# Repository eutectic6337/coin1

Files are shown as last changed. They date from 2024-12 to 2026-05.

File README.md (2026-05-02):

# coin1
challenge coin with blinky lights

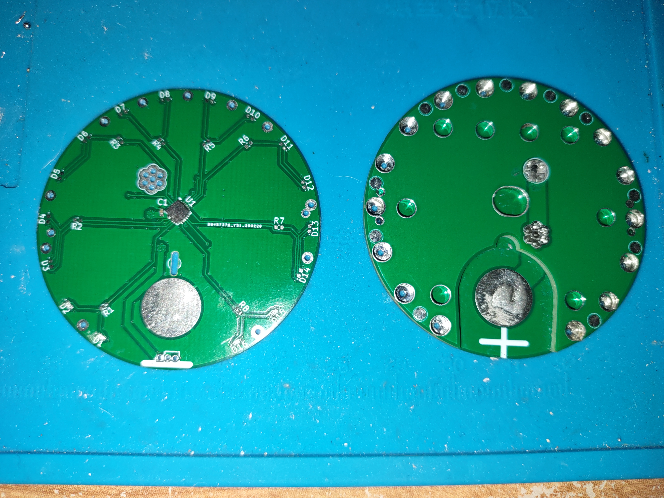
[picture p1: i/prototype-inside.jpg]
pre-DEFCON prototype, from the inside


Feature: Using 8 PWM channels to provide dimming function for 16 LEDs
by connecting pairs in anti-parallel between a PWM pin and a GPIO.

built as a stack of 3 PCBs -
components mounted on top of bottom board,
second board has a cutout to fit a battery and for each mounted component,
and top board has holes to transmit light from LEDs

finished coin to have [relatively] smooth top and bottom

using JLCPCB's serial-number mechanism to put a unique number on each coin

Initial code flashed onto these is
[a modified version of the Arduino Blink demo](software/Blink).

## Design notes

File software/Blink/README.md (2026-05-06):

# Blink

Arduino demo, modified to loop over 8 pairs of
anti-parallel-connected LEDs,
blinking each one on for 1ms and off for 99ms
before moving on to the next.

## How to build and flash the software on the chip

### What to get

- [Arduino IDE](https://www.arduino.cc/en/software/#ide)

- WCH compiler

  First, add the unofficial WCH repo: In Arduino IDE > File > Preferences > Additional Board Manager URLs > Click the 'Edit' icon on the far right side of the IDE (It looks like a copy button)
  Always double check the JSON by clicking 'Click for a list of unofficial board support URLs', but the .json link is listed below:
  https://raw.githubusercontent.com/openwch/board_manager_files/main/package_ch32v_index.json

  You must install v1.0.0 first or you will run into errors. After that, install v1.0.4. (If you run into issues, run the IDE with elevated privs)

  within Arduino IDE, select Tools / Board / Boards Manager

  search for "wch"

  install "CH32 MCU EVT Boards"

- [WCH-LinkUtility](https://www.wch.cn/downloads/WCH-LinkUtility_ZIP.html)
 programming tool

   (works on Linux under WINE)

- [WCH-LinkE](https://www.aliexpress.us/item/3256804695267285.html)
 USB programmer

- 3-pin 1.27mm spacing
 [pogo-pin PCB clip](https://www.aliexpress.us/item/3256806702127807.html)

- some Dupont-connector jumper wires

### What to do

- open this modified Blink sketch in Arduino environment, and compile it by clicking leftmost button "Verify"

  find the generated bin file (e.g. /home/user/.cache/arduino/sketches/40EA08CCBD0DF8AB898F31F63E3E5F1E/Blink.ino.bin)
                              (e.g. C:\Users\USER\AppData\Local\arduino\sketches\40C10A2A9890BEF7BEAD8C7F314D8C2A/sketch_[DATE].ino.bin)

- connect 3V, GND, and SWDIO pins on WCH-LinkE device to 3 pins on PCB clip,
 from right to left respectively, so the pogo pins can contact the pads on the
 back face of the coin (the back of the PCB with components mounted)

- plug WCH-LinkE in to USB port on PC

- run WCH-LinkUtility

  load the bin file (see above) using first button "Choose"
  connect to WCH-LinkE using second button "Connect" (should soon see status message similar to "Connected RISC-V mode WCH-Link Cnt:0")

  select Core "RISC-V"

  select Series "CH32V003"

- in "Operation" section

  check "Erase All", "Program", "Verify", "Reset and Run"

- in "Operation Configuration" section

  select "Disable MCU Code Read-Protect"

  select from dropdown CLK Speed "High"

- in "MCU Configuration" section

  check "Disable Standby-Mode RST" (Note: Need to clarify whether we're unchecking 'Starting From the Boot Area')

  select from dropdown "Disable mul-func,PD7 is used for IO function"

### then for each coin

- connect PCB clip to coin

  verify connection using third button "Query Chip Info"
 (should soon see status messages "Begin to set chip type...", "Begin to get chip version...", "Begin to get chip UID & flash size...")
")

  program chip using fourth button "Execute"
 (should soon see status messages "Begin to set chip type...", "Begin to Erase...", "Begin to Program and Verify...", "Begin to Reset...", "Operation is Successful")

  sit back und watchen das blinkenlights

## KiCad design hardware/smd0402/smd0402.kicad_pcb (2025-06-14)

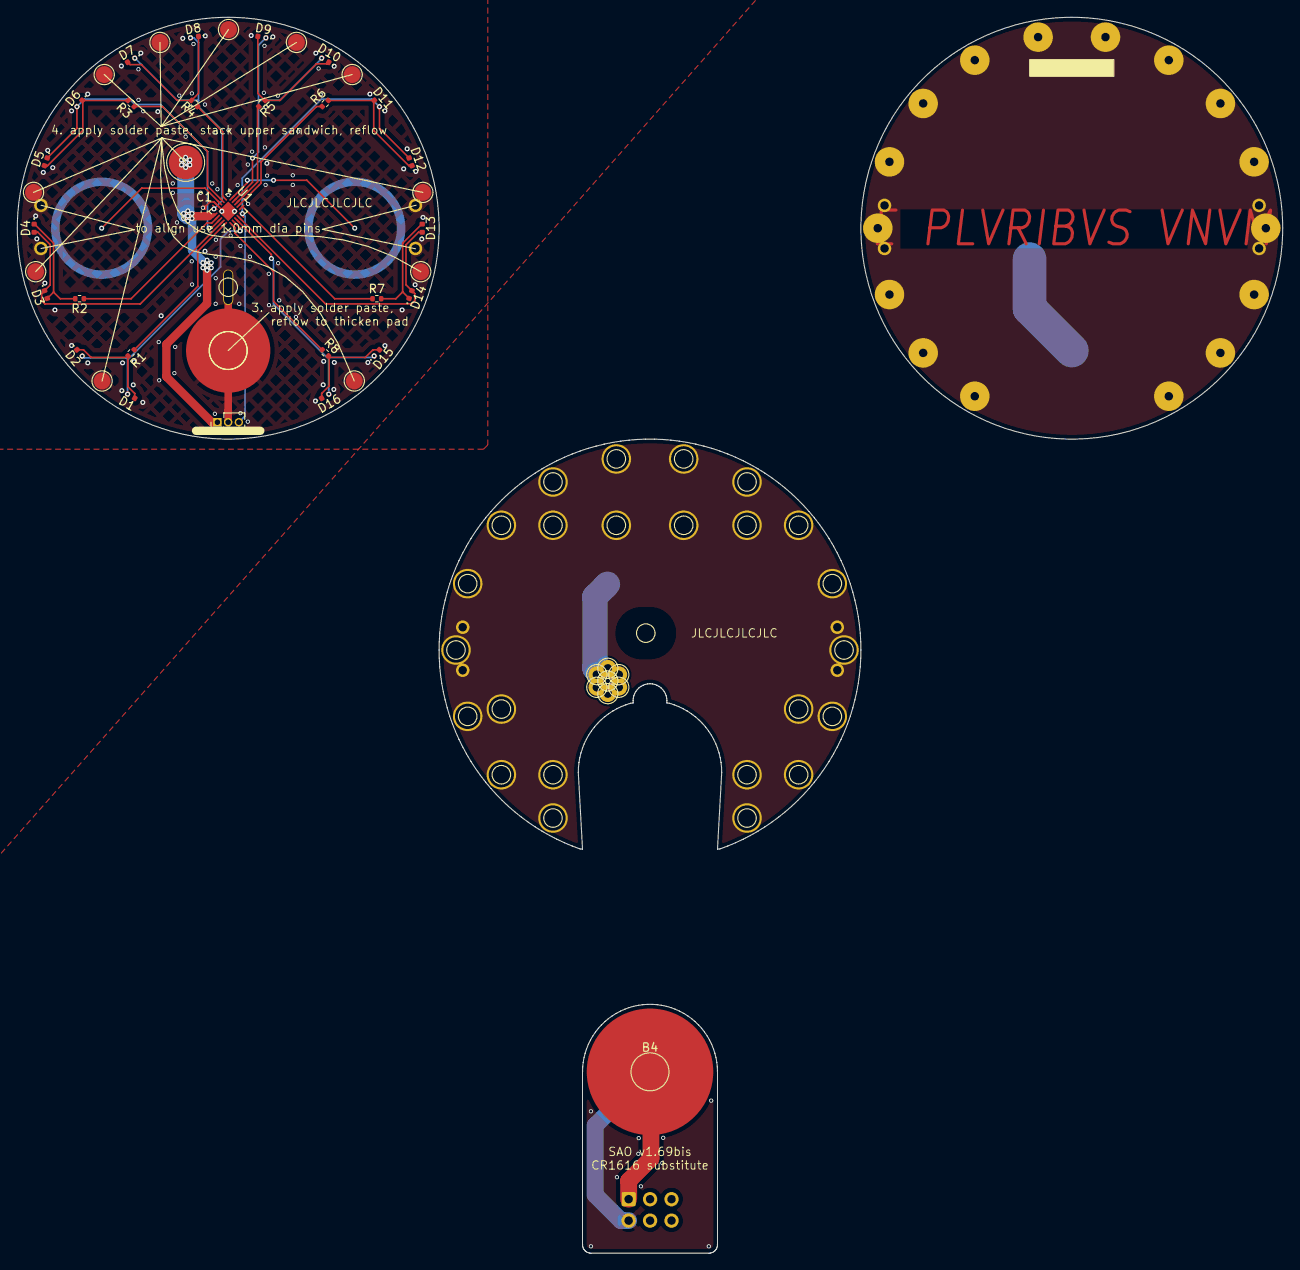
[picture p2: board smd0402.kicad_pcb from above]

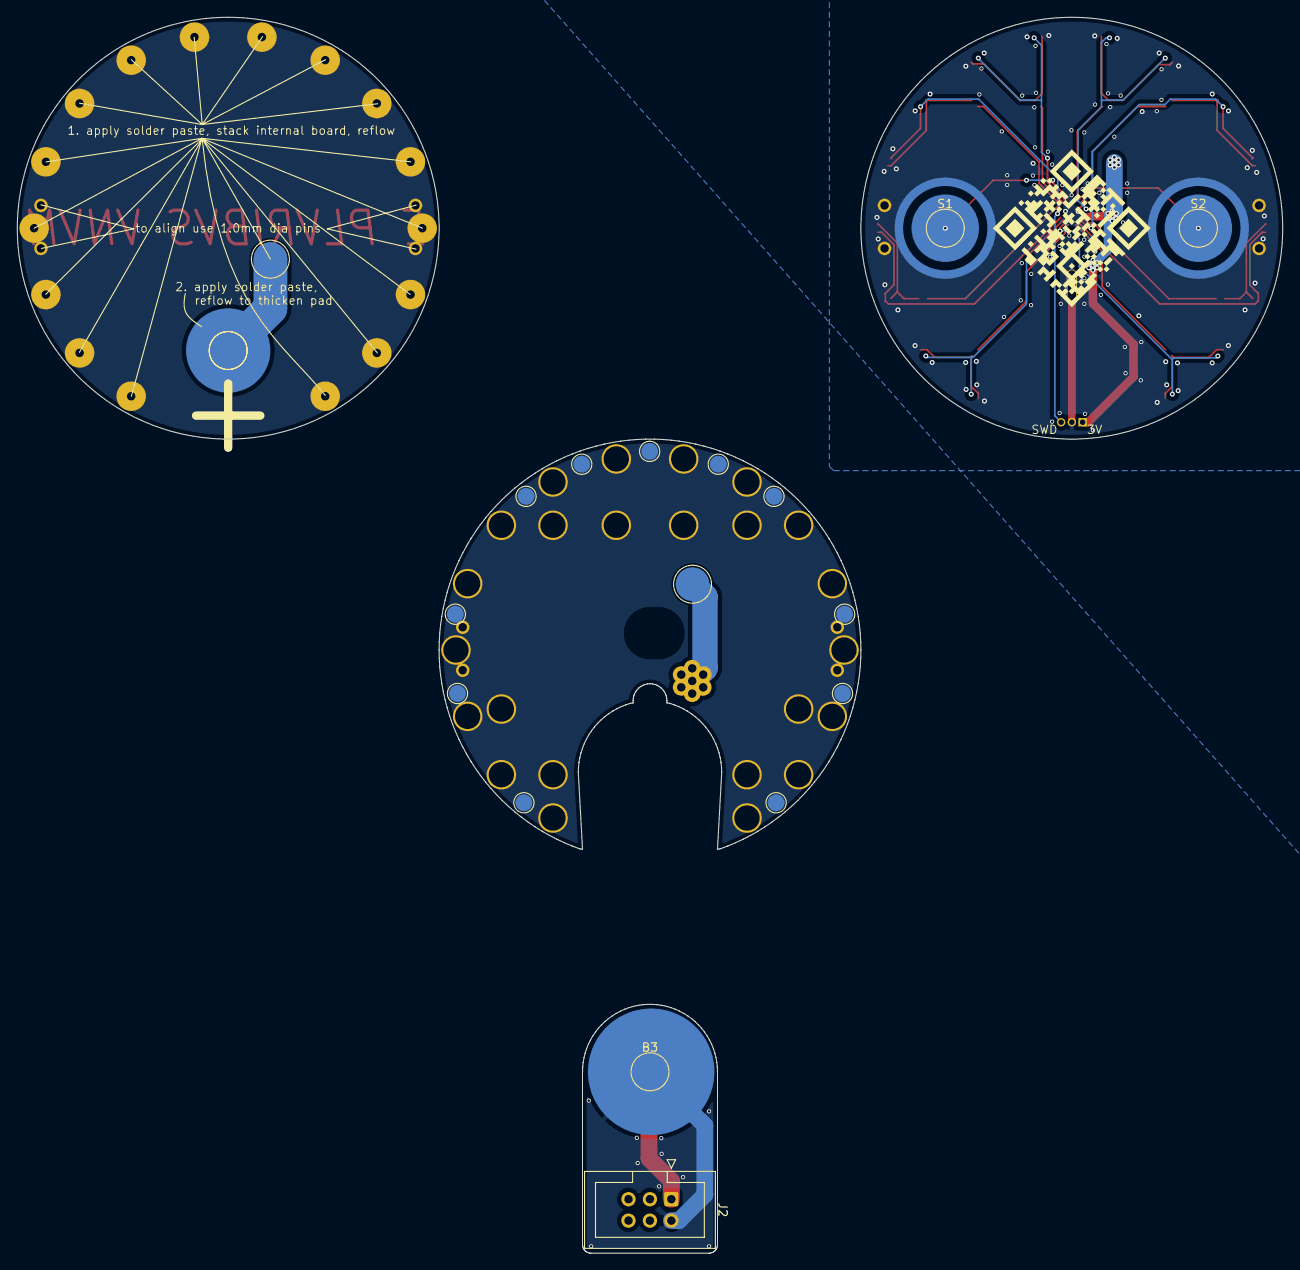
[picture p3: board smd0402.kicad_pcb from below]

Board: 2 copper layers, 150.0 x 146.5 mm, 124 parts (21 on the bottom side), 28 nets.

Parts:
+: BAT+; TestPoint_Pad_D4.0mm
-: BAT-; TestPoint_Pad_D4.0mm
B1, B3: BAT-; TestPoint_Pad_D4.0mm
B2, B4: BAT+; TestPoint_Pad_D4.0mm
C1: 1u; C_0402_1005Metric
D1, D2, D3, D4, D5, D6, D7, D8, D9, D10, D11, D12, D13, D14, D15, D16: LED; LED_0402_1005Metric
J1: Conn_01x03; PinHeader_1x03_P1.27mm_Vertical
J2: SAO v1.69bis addon; IDC-Header_2x03_P2.54mm_Vertical
R1, R2, R3, R4, R5, R6, R7, R8: 47R; R_0402_1005Metric
S1, S2: touch; TestPoint_Pad_D4.0mm
SAO-P1, SAO-P2: (no value)
U1: WCH CH32V003F4U6; QFN-20-1EP_3x3mm_P0.4mm_EP1.65x1.65mm
align-i1, align-i2, align-i3, align-i4: (no value)
align-o1, align-o2, align-o3, align-o4: (no value)
align-r1, align-r2, align-r3, align-r4: (no value)
aperture-D1, aperture-D2, aperture-D3, aperture-D4, aperture-D5, aperture-D6, aperture-D7, aperture-D8, aperture-D9, aperture-D10, aperture-D11, aperture-D12, aperture-D13, aperture-D14, aperture-D15, aperture-D16: TestPoint_THTPad_D1.0mm_Drill0.5mm
battery-eject1: TestPoint_THTPad_3.0x3.0mm_Drill1.5mm
clearance-D1, clearance-D2, clearance-D3, clearance-D4, clearance-D5, clearance-D6, clearance-D7, clearance-D8, clearance-D9, clearance-D10, clearance-D11, clearance-D12, clearance-D13, clearance-D14, clearance-D15, clearance-D16: TestPoint_THTPad_3.0x3.0mm_Drill1.5mm
clearance-R1, clearance-R2, clearance-R3, clearance-R4, clearance-R5, clearance-R6, clearance-R7, clearance-R8: TestPoint_THTPad_3.0x3.0mm_Drill1.5mm
clearance-U1: TestPoint_THTPad_3.0x3.0mm_Drill1.5mm
contact-i1: TestPoint_Pad_D4.0mm
contact-o1: TestPoint_Pad_D4.0mm
contact-r1: TestPoint_Pad_D4.0mm
stitch1, stitch1#2, stitch1#3, stitch1#4, stitch1#5, stitch1#6, stitch1#7, stitch1#8, stitch1#9, stitch1#10, stitch1#11, stitch2, stitch2#2, stitch2#3, stitch2#4, stitch2#5, stitch2#6, stitch2#7, stitch2#8, stitch2#9, stitch2#10, stitch2#11: TestPoint_Pad_D2.0mm
through-i1, through-i2, through-i3, through-i4, through-i5, through-i6, through-i7: TestPoint_THTPad_D2.0mm_Drill1.0mm

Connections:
+3V0: +.1, B2.1, B4.1, C1.1, J1.1, J2.1 (3V3), SAO-P1.1, U1.6 (VDD), contact-i1.1, contact-o1.1, contact-r1.1, through-i1.1, through-i2.1, through-i3.1, through-i4.1, through-i5.1, through-i6.1, through-i7.1
/touch1: S1.1, U1.20 (ADC_IN6)
/touch2: S2.1, U1.3 (ADC_IN0)
GND: -.1, B1.1, B3.1, C1.2, J1.2, J2.2 (GND), SAO-P2.1, U1.4 (VSS), U1.21 (VSS), align-i1.1, align-i2.1, align-i3.1, align-i4.1, align-o1.1, align-o2.1, align-o3.1, align-o4.1, align-r1.1, align-r2.1, align-r3.1, align-r4.1, aperture-D1.1, aperture-D2.1, aperture-D3.1, aperture-D4.1, aperture-D5.1, aperture-D6.1, aperture-D7.1, aperture-D8.1, aperture-D9.1, aperture-D10.1, aperture-D11.1, aperture-D12.1, aperture-D13.1, aperture-D14.1, aperture-D15.1, aperture-D16.1, battery-eject1.1, clearance-D1.1, clearance-D2.1, clearance-D3.1, clearance-D4.1, clearance-D5.1, clearance-D6.1, clearance-D7.1, clearance-D8.1, clearance-D9.1, clearance-D10.1, clearance-D11.1, clearance-D12.1, clearance-D13.1, clearance-D14.1, clearance-D15.1, clearance-D16.1, stitch1.1, stitch1#2.1, stitch1#3.1, stitch1#4.1, stitch1#5.1, stitch1#6.1, stitch1#7.1, stitch1#8.1, stitch1#9.1, stitch1#10.1, stitch1#11.1, stitch2.1, stitch2#2.1, stitch2#3.1, stitch2#4.1, stitch2#5.1, stitch2#6.1, stitch2#7.1, stitch2#8.1, stitch2#9.1, stitch2#10.1, stitch2#11.1
GP1: D1.1 (K), D2.2 (A), U1.12 (PC5)
GP2: D3.1 (K), D4.2 (A), U1.9 (PC2)
GP3: D5.1 (K), D6.2 (A), U1.8 (PC1)
GP4: D7.1 (K), D8.2 (A), U1.5 (PD0)
GP5: D9.1 (K), D10.2 (A), U1.19 (PD5)
GP6: D11.1 (K), D12.2 (A), J1.3, U1.15 (SWIO)
GP7: D13.1 (K), D14.2 (A), U1.14 (PC7)
GP8: D15.1 (K), D16.2 (A), U1.13 (PC6)
unnamed: D1.2 (A), D2.1 (K), R1.2
unnamed: D3.2 (A), D4.1 (K), R2.2
unnamed: D5.2 (A), D6.1 (K), R3.2
unnamed: D7.2 (A), D8.1 (K), R4.2
unnamed: D9.2 (A), D10.1 (K), R5.2
unnamed: D11.2 (A), D12.1 (K), R6.2
unnamed: D13.2 (A), D14.1 (K), R7.2
unnamed: D15.2 (A), D16.1 (K), R8.2
PWM1: R1.1, U1.10 (TIM1_CH3)
PWM2: R2.1, U1.7 (TIM2_CH3)
PWM3: R3.1, U1.2 (TIM1_CH2)
PWM4: R4.1, U1.1 (TIM2_CH4)
PWM5: R5.1, U1.18 (TIM2_CH1)
PWM6: R6.1, U1.17 (TIM2_CH2)
PWM7: R7.1, U1.16 (TIM1_CH1)
PWM8: R8.1, U1.11 (TIM1_CH4)

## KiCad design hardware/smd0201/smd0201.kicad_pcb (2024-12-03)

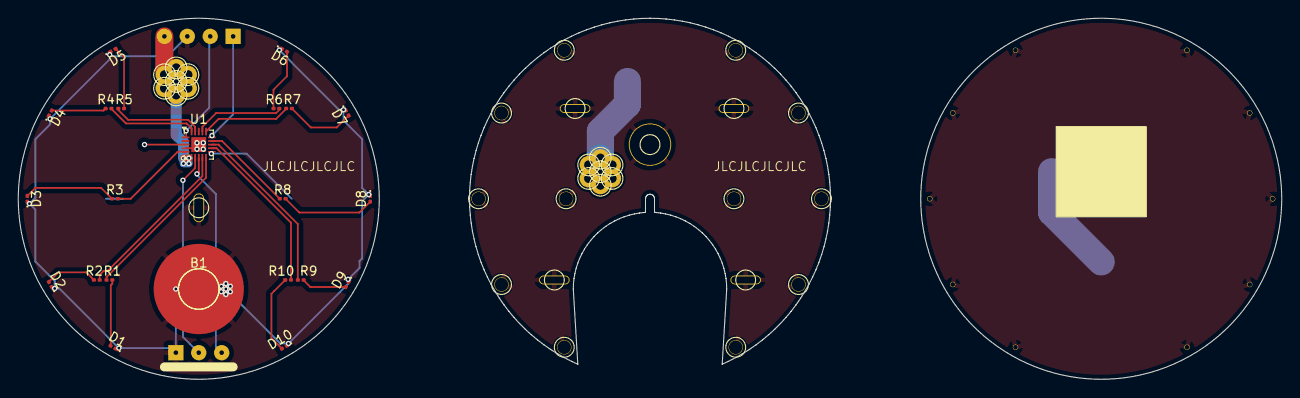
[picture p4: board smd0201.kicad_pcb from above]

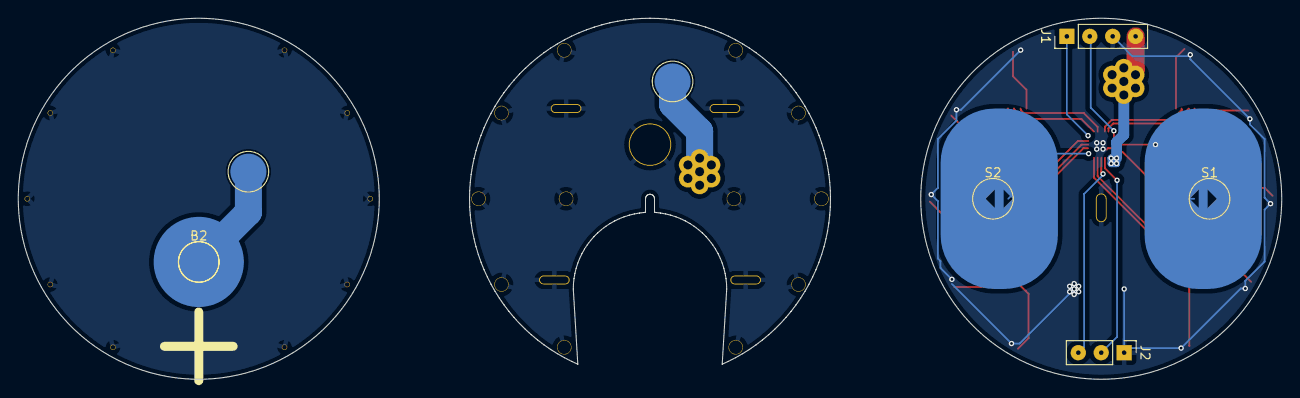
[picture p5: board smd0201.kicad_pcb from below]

Board: 2 copper layers, 140.0 x 40.0 mm, 71 parts (6 on the bottom side), 28 nets.

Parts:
+: BAT+; TestPoint_Pad_D4.0mm
-: BAT-; TestPoint_Pad_D4.0mm
B1: BAT-; TestPoint_Pad_D4.0mm
B2: BAT+; TestPoint_Pad_D4.0mm
D1, D2, D3, D4, D5, D6, D7, D8, D9, D10: LED; LED_0201_0603Metric
J1: Conn_01x04; PinHeader_1x04_P2.54mm_Vertical
J2: Conn_01x03; PinHeader_1x03_P2.54mm_Vertical
R1, R2, R3, R4, R5, R6, R7, R8, R9, R10: 47R; R_0201_0603Metric
S1, S2: touch; TestPoint_Pad_D4.0mm
T1, T1#2, T2, T3, T4, T5, T6, T8, T9, T9#2, T9#3, T9#4, T9#5, T9#6, T9#7, T10, T11, T12: TestPoint_THTPad_3.0x3.0mm_Drill1.5mm
T22, T23, T24, T25, T26, T28, T29, T30, T31, T32: TestPoint_THTPad_D1.0mm_Drill0.5mm
T51, T51#2, T51#3, T51#4, T52, T52#2, T53, T53#2, T54, T54#2, T55, T55#2, T56, T56#2: TestPoint_THTPad_D2.0mm_Drill1.0mm
U1: WCH CH32V003F4U6; QFN-20-1EP_3x3mm_P0.4mm_EP1.65x1.65mm

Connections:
+3V0: +.1, B2.1, J1.4, T51.1, T51#2.1, T51#3.1, T51#4.1, T52.1, T52#2.1, T53.1, T53#2.1, T54.1, T54#2.1, T55.1, T55#2.1, T56.1, T56#2.1, U1.6 (VDD)
/LED1: R1.1, U1.10 (PC3)
/LED2: R2.1, U1.9 (PC2)
/LED3: R3.1, U1.5 (PD0)
/LED4: R4.1, U1.20 (PD6)
/LED5: R5.1, U1.19 (PD5)
/LED6: R6.1, U1.17 (PD3)
/LED7: R7.1, U1.16 (PD2)
/LED8: R8.1, U1.14 (PC7)
/LED9: R9.1, U1.13 (PC6)
/LED10: R10.1, U1.12 (PC5)
/NRST: J1.2, U1.1 (NRST)
/RX: J2.3, U1.8 (USART_RX_3)
/SWIO: J1.1, U1.15 (SWIO)
/TX: J2.2, U1.7 (USART_TX_3)
/touch1: S1.1, U1.3 (ADC_IN0)
/touch2: S2.1, U1.11 (ADC_IN2)
GND: -.1, B1.1, D1.1 (K), D2.1 (K), D3.1 (K), D4.1 (K), D5.1 (K), D6.1 (K), D7.1 (K), D8.1 (K), D9.1 (K), D10.1 (K), J1.3, J2.1, T1.1, T1#2.1, T2.1, T3.1, T4.1, T5.1, T6.1, T8.1, T9.1, T9#2.1, T9#3.1, T9#4.1, T9#5.1, T9#6.1, T9#7.1, T10.1, T11.1, T12.1, T22.1, T23.1, T24.1, T25.1, T26.1, T28.1, T29.1, T30.1, T31.1, T32.1, U1.4 (VSS)
unnamed: D1.2 (A), R1.2
unnamed: D2.2 (A), R2.2
unnamed: D3.2 (A), R3.2
unnamed: D4.2 (A), R4.2
unnamed: D5.2 (A), R5.2
unnamed: D6.2 (A), R6.2
unnamed: D7.2 (A), R7.2
unnamed: D8.2 (A), R8.2
unnamed: D9.2 (A), R9.2
unnamed: D10.2 (A), R10.2

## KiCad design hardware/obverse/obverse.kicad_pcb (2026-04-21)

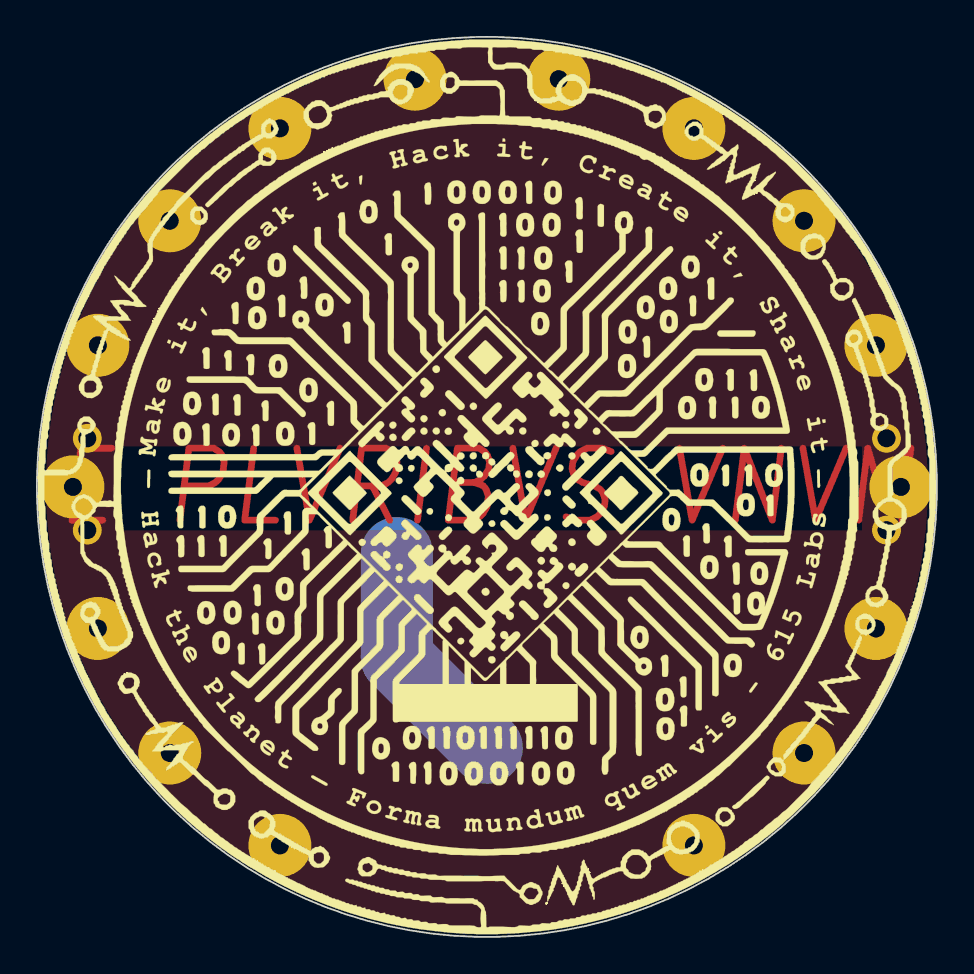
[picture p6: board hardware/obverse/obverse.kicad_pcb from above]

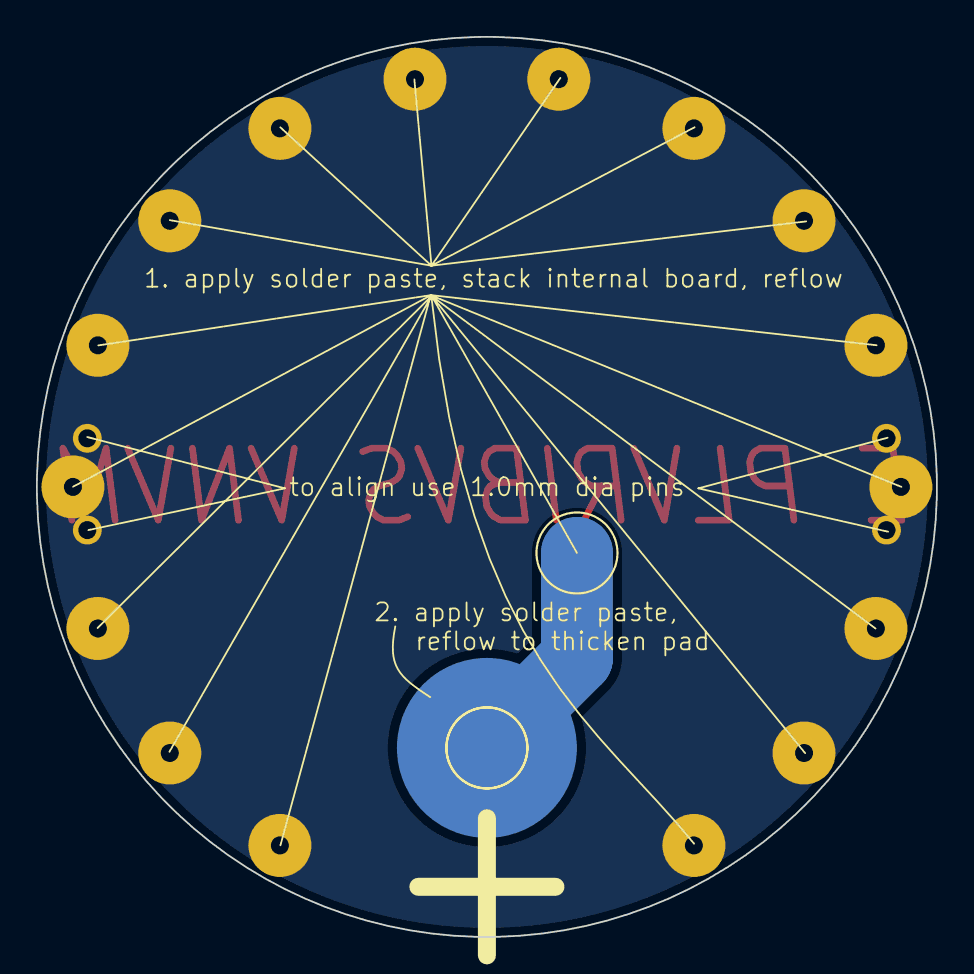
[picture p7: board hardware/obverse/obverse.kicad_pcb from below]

Board: 2 copper layers, 50.0 x 50.0 mm, 23 parts (3 on the bottom side), 2 nets.

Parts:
+: BAT+; TestPoint_Pad_D4.0mm
B2: BAT+; TestPoint_Pad_D4.0mm
align-o1, align-o2, align-o3, align-o4: (no value)
aperture-D1, aperture-D2, aperture-D3, aperture-D4, aperture-D5, aperture-D6, aperture-D7, aperture-D8, aperture-D9, aperture-D10, aperture-D11, aperture-D12, aperture-D13, aperture-D14, aperture-D15, aperture-D16: TestPoint_THTPad_D1.0mm_Drill0.5mm
contact-o1: TestPoint_Pad_D4.0mm

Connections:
+3V0: +.1, B2.1, contact-o1.1
GND: align-o1.1, align-o2.1, align-o3.1, align-o4.1, aperture-D1.1, aperture-D2.1, aperture-D3.1, aperture-D4.1, aperture-D5.1, aperture-D6.1, aperture-D7.1, aperture-D8.1, aperture-D9.1, aperture-D10.1, aperture-D11.1, aperture-D12.1, aperture-D13.1, aperture-D14.1, aperture-D15.1, aperture-D16.1

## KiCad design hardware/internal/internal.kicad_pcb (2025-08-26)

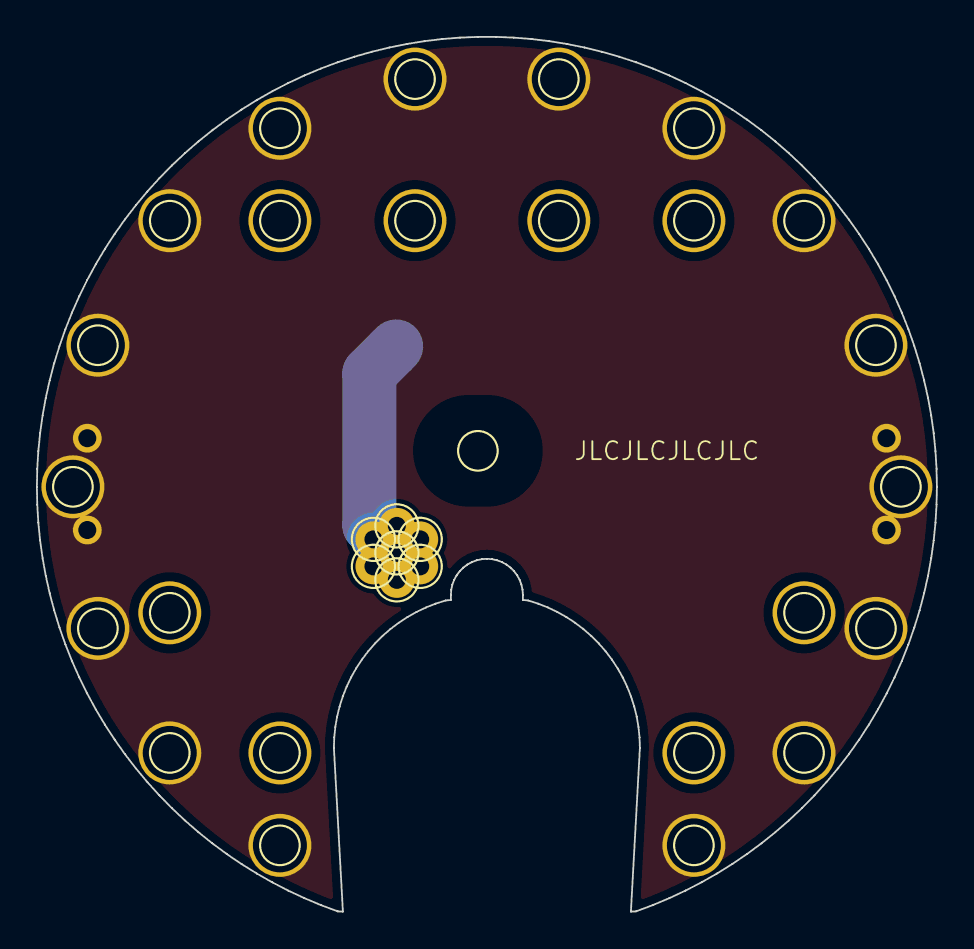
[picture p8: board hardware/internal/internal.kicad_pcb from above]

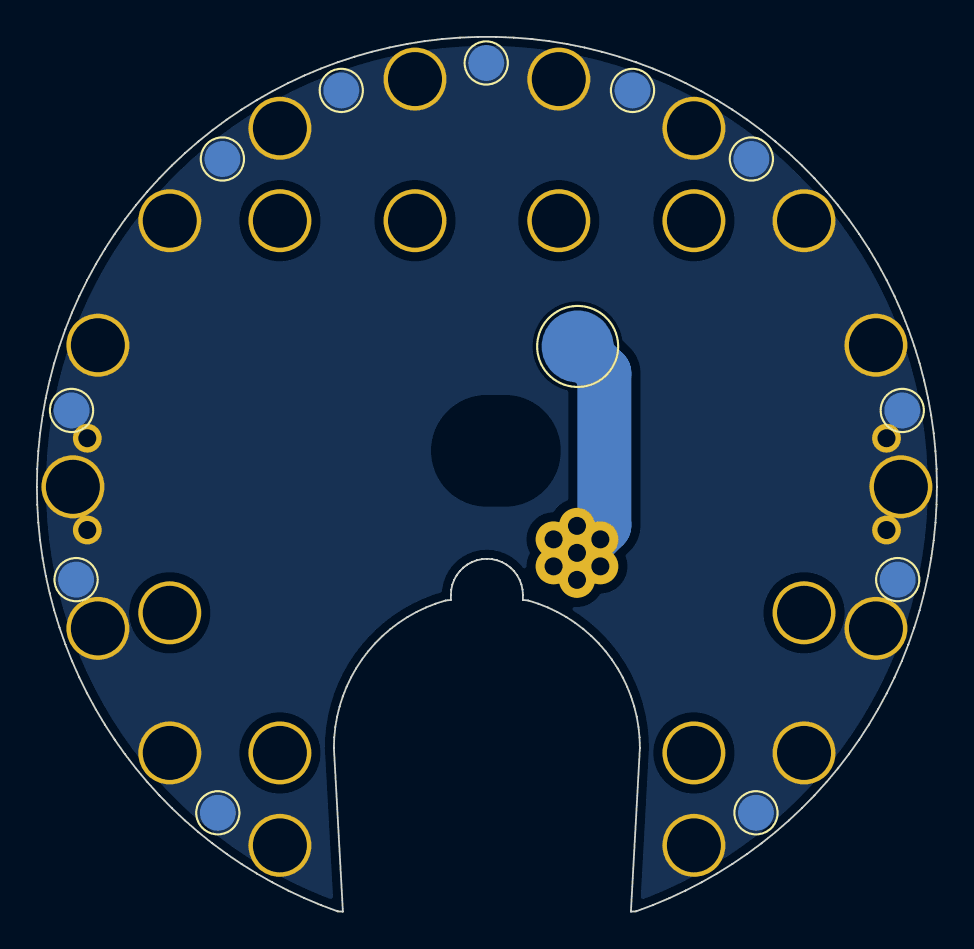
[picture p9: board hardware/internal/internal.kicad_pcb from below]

Board: 2 copper layers, 50.0 x 48.6 mm, 48 parts (12 on the bottom side), 2 nets.

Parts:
align-i1, align-i2, align-i3, align-i4: (no value)
clearance-D1, clearance-D2, clearance-D3, clearance-D4, clearance-D5, clearance-D6, clearance-D7, clearance-D8, clearance-D9, clearance-D10, clearance-D11, clearance-D12, clearance-D13, clearance-D14, clearance-D15, clearance-D16: TestPoint_THTPad_3.0x3.0mm_Drill1.5mm
clearance-R1, clearance-R2, clearance-R3, clearance-R4, clearance-R5, clearance-R6, clearance-R7, clearance-R8: TestPoint_THTPad_3.0x3.0mm_Drill1.5mm
clearance-U1: TestPoint_THTPad_3.0x3.0mm_Drill1.5mm
contact-i1: TestPoint_Pad_D4.0mm
stitch2, stitch2#2, stitch2#3, stitch2#4, stitch2#5, stitch2#6, stitch2#7, stitch2#8, stitch2#9, stitch2#10, stitch2#11: TestPoint_Pad_D2.0mm
through-i1, through-i2, through-i3, through-i4, through-i5, through-i6, through-i7: TestPoint_THTPad_D2.0mm_Drill1.0mm

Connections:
+3V0: contact-i1.1, through-i1.1, through-i2.1, through-i3.1, through-i4.1, through-i5.1, through-i6.1, through-i7.1
GND: align-i1.1, align-i2.1, align-i3.1, align-i4.1, clearance-D1.1, clearance-D2.1, clearance-D3.1, clearance-D4.1, clearance-D5.1, clearance-D6.1, clearance-D7.1, clearance-D8.1, clearance-D9.1, clearance-D10.1, clearance-D11.1, clearance-D12.1, clearance-D13.1, clearance-D14.1, clearance-D15.1, clearance-D16.1, stitch2.1, stitch2#2.1, stitch2#3.1, stitch2#4.1, stitch2#5.1, stitch2#6.1, stitch2#7.1, stitch2#8.1, stitch2#9.1, stitch2#10.1, stitch2#11.1

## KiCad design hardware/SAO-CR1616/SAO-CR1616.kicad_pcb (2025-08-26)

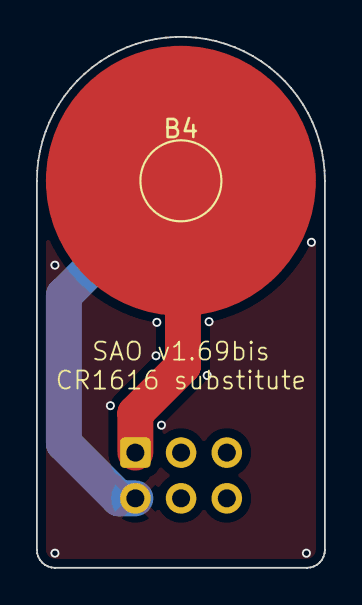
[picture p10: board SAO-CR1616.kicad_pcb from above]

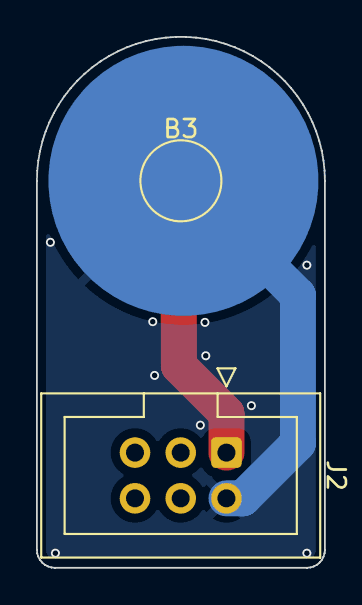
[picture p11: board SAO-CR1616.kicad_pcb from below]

Board: 2 copper layers, 16.0 x 29.5 mm, 5 parts (4 on the bottom side), 2 nets.

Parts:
B3: BAT-; TestPoint_Pad_D4.0mm
B4: BAT+; TestPoint_Pad_D4.0mm
J2: SAO v1.69bis addon; IDC-Header_2x03_P2.54mm_Vertical
SAO-P1, SAO-P2: (no value)

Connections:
+3V0: B4.1, J2.1 (3V3), SAO-P1.1
GND: B3.1, J2.2 (GND), SAO-P2.1

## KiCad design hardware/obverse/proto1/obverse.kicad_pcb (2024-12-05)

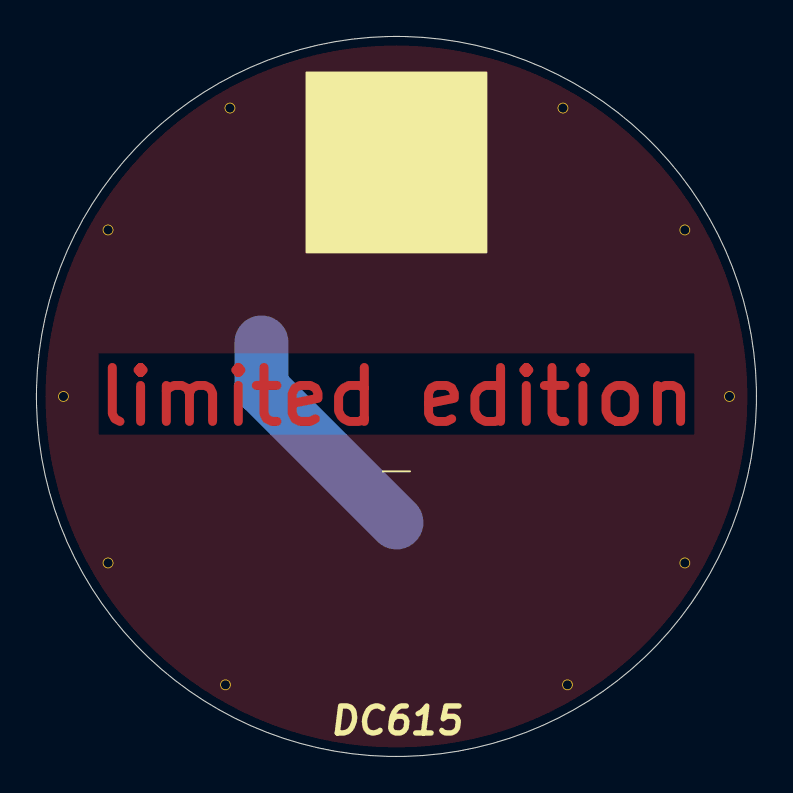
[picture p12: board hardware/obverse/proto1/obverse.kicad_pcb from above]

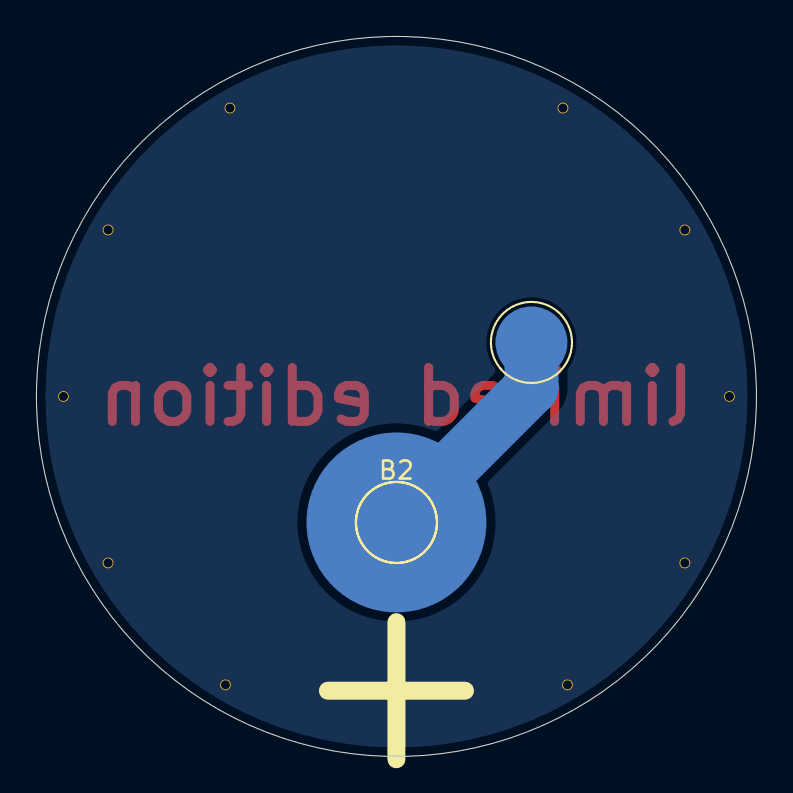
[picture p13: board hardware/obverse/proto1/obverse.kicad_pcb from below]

Board: 2 copper layers, 40.0 x 40.0 mm, 12 parts (2 on the bottom side), 2 nets.

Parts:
+: BAT+; TestPoint_Pad_D4.0mm
B2: BAT+; TestPoint_Pad_D4.0mm
T42, T43, T44, T45, T46, T48, T49, T50, T51, T52: TestPoint_THTPad_D1.0mm_Drill0.5mm

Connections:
+3V0: +.1, B2.1
GND: T42.1, T43.1, T44.1, T45.1, T46.1, T48.1, T49.1, T50.1, T51.1, T52.1

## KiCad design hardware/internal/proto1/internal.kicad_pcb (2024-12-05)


Board: 2 copper layers, 40.0 x 38.3 mm, 24 parts (0 on the bottom side), 2 nets.

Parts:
T1, T12, T13, T14, T15, T16, T18, T19, T20, T21, T21#2, T21#3, T21#4, T21#5, T21#6, T21#7, T22: TestPoint_THTPad_3.0x3.0mm_Drill1.5mm
T51, T51#2, T52, T53, T54, T55, T56: TestPoint_THTPad_D2.0mm_Drill1.0mm

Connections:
+3V0: T51.1, T51#2.1, T52.1, T53.1, T54.1, T55.1, T56.1
GND: T1.1, T12.1, T13.1, T14.1, T15.1, T16.1, T18.1, T19.1, T20.1, T21.1, T21#2.1, T21#3.1, T21#4.1, T21#5.1, T21#6.1, T21#7.1, T22.1

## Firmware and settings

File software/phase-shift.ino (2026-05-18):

/*
  CH32V003 Random Circle Pulse Pattern
  Delayed-Overlap Origin-Based Handoff
  No peak hold / 60% brightness cap

  Behavior:
  - Starts from one single origin LED
  - Excludes D11 and D12 entirely
  - Randomly passes light between D1-D10 and D13-D16
  - Prevents same diode from repeating back-to-back
  - Prevents adjacent physical diodes from being selected as the next handoff
  - Uses delayed overlap:
      current LED fades out alone
      when current LED is ~75% through its fade-out, next LED starts fading in
  - Removes the peak hold to avoid visible blinking/stutter at max brightness
  - Hard-caps all brightness at 60%
  - Keeps original pin declaration pattern
  - Keeps PD7 in original position
  - Does NOT rewrite option bytes

  WCH-LinkUtility:
  - PD7 should be configured as:
    "Disable mul-func, PD7 used for IO function"
*/

#define NUM_ARRAY_ELEMS(a) ((sizeof(a)) / (sizeof((a)[0])))

struct pin_pair {
  int p1;
  int p2;
};

struct diode_drive {
  int diodeNumber;
  int highPin;
  int lowPin;
};

const pin_pair LED_pair_pins[] = {
  {PC5, PC3/*TIM1_CH3*/},            // D1 / D2
  {PC2, PC0/*TIM2_CH3*/},            // D3 / D4
  {PC1, PA1/*TIM1_CH2*/},            // D5 / D6
  {PD0, PD7/*TIM2_CH4*/},            // D7 / D8
  {PD5, PD4/*TIM2_CH1*/},            // D9 / D10
  {PD1/*SWIO*/, PD3/*TIM2_CH2*/},    // D11 / D12 - EXCLUDED
  {PC7, PD2/*TIM1_CH1*/},            // D13 / D14
  {PC6, PC4/*TIM1_CH4*/},            // D15 / D16
};

const int ALL_LED_PINS[] = {
  PC5, PC3,
  PC2, PC0,
  PC1, PA1,
  PD0, PD7,
  PD5, PD4,
  PD1, PD3,
  PC7, PD2,
  PC6, PC4
};

/*
  Physical diode order correction based on observed board behavior:

  For each pair:
  - Odd diode  = p2 HIGH, p1 LOW
  - Even diode = p1 HIGH, p2 LOW

  D11/D12 are intentionally omitted.
*/
const diode_drive DIODES[] = {
  {1,  PC3, PC5},
  {2,  PC5, PC3},

  {3,  PC0, PC2},
  {4,  PC2, PC0},

  {5,  PA1, PC1},
  {6,  PC1, PA1},

  {7,  PD7, PD0},
  {8,  PD0, PD7},

  {9,  PD4, PD5},
  {10, PD5, PD4},

  // D11 / D12 skipped entirely

  {13, PD2, PC7},
  {14, PC7, PD2},

  {15, PC4, PC6},
  {16, PC6, PC4},
};

/*
  Origin point.
  Valid options here: 1-10, 13-16.
*/
const int ORIGIN_DIODE = 1;

/*
  Brightness cap.
*/
const int MIN_DUTY_PERCENT = 3;
const int MAX_DUTY_PERCENT = 60;

/*
  More steps = smoother fade.
*/
const int HANDOFF_STEPS = 72;

/*
  Next LED starts when current LED is this far through its fade-out.
  75 = next LED starts at 3/4 through the current LED's cycle.
*/
const int OVERLAP_START_PERCENT = 75;

/*
  Handoff timing.
*/
const unsigned int STEP_HOLD_MS = 24;

/*
  Faster PWM reduces visible flicker/stutter.
  250us = ~4kHz software PWM target before overhead.
*/
const unsigned int PWM_PERIOD_US = 250;

/*
  Origin timing.
*/
const unsigned int ORIGIN_FADE_IN_HOLD_MS = 24;
const unsigned int ORIGIN_HOLD_MS         = 900;

/*
  No peak hold.
*/
const unsigned int HOLD_AFTER_PASS_MS = 20;
const unsigned int LOOP_GAP_MS        = 10;
const unsigned int STARTUP_WAIT_MS    = 1000;

int currentIndex = 0;

int clampDuty(int dutyPercent) {
  if (dutyPercent < 0) {
    return 0;
  }

  if (dutyPercent > MAX_DUTY_PERCENT) {
    return MAX_DUTY_PERCENT;
  }

  return dutyPercent;
}

void enableAFIOClock() {
  #ifdef RCC_APB2Periph_AFIO
    RCC->APB2PCENR |= RCC_APB2Periph_AFIO;
  #elif defined(RCC_AFIOEN)
    RCC->APB2PCENR |= RCC_AFIOEN;
  #else
    RCC->APB2PCENR |= 0x00000001;
  #endif
}

void use_PA1_mode() {
  /*
    PA1-friendly mode.
    Keeps D5/D6 working.
  */
  enableAFIOClock();
  AFIO->PCFR1 &= ~(1 << 15);
}

void allPinsHiZ() {
  for (int i = 0; i < NUM_ARRAY_ELEMS(ALL_LED_PINS); i++) {
    digitalWrite(ALL_LED_PINS[i], LOW);
    pinMode(ALL_LED_PINS[i], INPUT);
  }
}

void setupDiodePins(int highPin, int lowPin) {
  pinMode(lowPin, OUTPUT);
  digitalWrite(lowPin, LOW);

  pinMode(highPin, OUTPUT);
  digitalWrite(highPin, HIGH);
}

void pulseOnePWMWindow(int highPin, int lowPin, int dutyPercent) {
  /*
    This is the only function that actually lights an LED.
    Duty is clamped here, so nothing should exceed 60%.
  */

  dutyPercent = clampDuty(dutyPercent);

  if (dutyPercent <= 0) {
    allPinsHiZ();
    delayMicroseconds(PWM_PERIOD_US);
    return;
  }

  unsigned int onTimeUs  = (PWM_PERIOD_US * dutyPercent) / 100;
  unsigned int offTimeUs = PWM_PERIOD_US - onTimeUs;

  setupDiodePins(highPin, lowPin);
  delayMicroseconds(onTimeUs);

  allPinsHiZ();

  if (offTimeUs > 0) {
    delayMicroseconds(offTimeUs);
  }
}

void holdDiode(int diodeIndex, int dutyPercent, unsigned int holdMs) {
  int highPin = DIODES[diodeIndex].highPin;
  int lowPin  = DIODES[diodeIndex].lowPin;

  dutyPercent = clampDuty(dutyPercent);

  unsigned long endTime = millis() + holdMs;

  while (millis() < endTime) {
    pulseOnePWMWindow(highPin, lowPin, dutyPercent);
  }

  allPinsHiZ();
}

void fadeInOrigin(int diodeIndex) {
  int highPin = DIODES[diodeIndex].highPin;
  int lowPin  = DIODES[diodeIndex].lowPin;

  for (int duty = MIN_DUTY_PERCENT; duty <= MAX_DUTY_PERCENT; duty++) {
    unsigned long endTime = millis() + ORIGIN_FADE_IN_HOLD_MS;

    while (millis() < endTime) {
      pulseOnePWMWindow(highPin, lowPin, duty);
    }
  }

  allPinsHiZ();
}

void delayedOverlapHandoff(int fromIndex, int toIndex) {
  /*
    Handoff logic:

    0% -> 75%:
      - Current LED fades down alone.
      - Next LED is off.

    75% -> 100%:
      - Current LED continues fading down.
      - Next LED fades up.

    No peak hold:
      - Avoids visible blink/stutter at max brightness.
  */

  int fromHigh = DIODES[fromIndex].highPin;
  int fromLow  = DIODES[fromIndex].lowPin;

  int toHigh = DIODES[toIndex].highPin;
  int toLow  = DIODES[toIndex].lowPin;

  int overlapStartStep = (HANDOFF_STEPS * OVERLAP_START_PERCENT) / 100;

  for (int step = 0; step <= HANDOFF_STEPS; step++) {
    int fromDuty = map(step, 0, HANDOFF_STEPS, MAX_DUTY_PERCENT, MIN_DUTY_PERCENT);
    fromDuty = clampDuty(fromDuty);

    int toDuty = 0;

    if (step >= overlapStartStep) {
      toDuty = map(step, overlapStartStep, HANDOFF_STEPS, MIN_DUTY_PERCENT, MAX_DUTY_PERCENT);
      toDuty = clampDuty(toDuty);
    }

    unsigned long endTime = millis() + STEP_HOLD_MS;

    while (millis() < endTime) {
      if (fromDuty > 0) {
        pulseOnePWMWindow(fromHigh, fromLow, fromDuty);
      }

      if (toDuty > 0) {
        pulseOnePWMWindow(toHigh, toLow, toDuty);
      }
    }
  }

  /*
    No max-brightness hold here.
    The next diode immediately becomes the new source for the next handoff.
  */
  allPinsHiZ();
  delay(HOLD_AFTER_PASS_MS);
}

int wrapIndex(int idx) {
  int count = NUM_ARRAY_ELEMS(DIODES);

  while (idx < 0) {
    idx += count;
  }

  while (idx >= count) {
    idx -= count;
  }

  return idx;
}

int findDiodeIndexByNumber(int diodeNumber) {
  for (int i = 0; i < NUM_ARRAY_ELEMS(DIODES); i++) {
    if (DIODES[i].diodeNumber == diodeNumber) {
      return i;
    }
  }

  return 0;
}

bool areAdjacentDiodes(int diodeA, int diodeB) {
  /*
    Physical circle adjacency.

    D1 is adjacent to D2 and D16.
    D16 is adjacent to D15 and D1.

    D11/D12 are excluded from the usable list,
    but they still exist physically, so:
      D10 is adjacent to D9 and D11, not D13.
      D13 is adjacent to D12 and D14, not D10.
  */

  if (diodeA == diodeB) {
    return true;
  }

  int diff = abs(diodeA - diodeB);

  if (diff == 1) {
    return true;
  }

  if (diff == 15) {
    return true;
  }

  return false;
}

bool isValidNextIndex(int candidateIndex) {
  int currentDiode   = DIODES[currentIndex].diodeNumber;
  int candidateDiode = DIODES[candidateIndex].diodeNumber;

  // No same-light repeat
  if (candidateIndex == currentIndex) {
    return false;
  }

  // No adjacent physical diode handoff
  if (areAdjacentDiodes(currentDiode, candidateDiode)) {
    return false;
  }

  return true;
}

int chooseNextIndex() {
  int count = NUM_ARRAY_ELEMS(DIODES);

  /*
    Random non-adjacent handoff:
    - No same-light repeat
    - No adjacent physical diode
    - D11/D12 impossible because they are not in DIODES[]
  */

  for (int attempts = 0; attempts < 50; attempts++) {
    int candidateIndex = random(count);

    if (isValidNextIndex(candidateIndex)) {
      return candidateIndex;
    }
  }

  /*
    Fallback: walk until a valid non-adjacent diode is found.
  */
  for (int offset = 2; offset < count; offset++) {
    int candidateIndex = wrapIndex(currentIndex + offset);

    if (isValidNextIndex(candidateIndex)) {
      return candidateIndex;
    }
  }

  return currentIndex;
}

void setup() {
  delay(STARTUP_WAIT_MS);

  enableAFIOClock();
  use_PA1_mode();
  allPinsHiZ();

  randomSeed(micros());

  currentIndex = findDiodeIndexByNumber(ORIGIN_DIODE);

  /*
    Point of origin:
    Start with only one LED.
  */
  fadeInOrigin(currentIndex);
  holdDiode(currentIndex, MAX_DUTY_PERCENT, ORIGIN_HOLD_MS);

  allPinsHiZ();

  /*
    Do NOT rewrite option bytes here.

    PD7 should be configured in WCH-LinkUtility:
    "Disable mul-func, PD7 used for IO function"
  */
}

void loop() {
  use_PA1_mode();

  int nextIndex = chooseNextIndex();

  delayedOverlapHandoff(currentIndex, nextIndex);

  currentIndex = nextIndex;

  delay(LOOP_GAP_MS);
}

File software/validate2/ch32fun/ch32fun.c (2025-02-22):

// Mixture of embedlibc, and ch32v00x_startup.c
// Use with newlib headers.
// Mixture of weblibc, mini-printf and ???
/* This file contains the following functions:

// libc (via musl) mixture and miniprintf

int printf( const char* format, ... )
int vprintf(const char* format, va_list args)
int snprintf( char * buffer, unsigned int buffer_len, const char* format, ... )
int sprintf( char * buffer, const char * format, ... )
size_t wcrtomb(char *restrict s, wchar_t wc, mbstate_t *restrict st)
int wctomb(char *s, wchar_t wc)
size_t strlen(const char *s)
size_t strnlen(const char *s, size_t n)
void *memset(void *dest, int c, size_t n)
char *strcpy(char *d, const char *s)
char *strncpy(char *d, const char *s, size_t n)
int strcmp(const char *l, const char *r)
int strncmp(const char *_l, const char *_r, size_t n)
static char *twobyte_strstr(const unsigned char *h, const unsigned char *n)
static char *threebyte_strstr(const unsigned char *h, const unsigned char *n)
static char *fourbyte_strstr(const unsigned char *h, const unsigned char *n)
static char *twoway_strstr(const unsigned char *h, const unsigned char *n)
char *strstr(const char *h, const char *n)
char *strchr(const char *s, int c)
void *__memrchr(const void *m, int c, size_t n)
char *strrchr(const char *s, int c)
void *memcpy(void *dest, const void *src, size_t n)
int memcmp(const void *vl, const void *vr, size_t n)
void *memmove(void *dest, const void *src, size_t n)
void *memchr(const void *src, int c, size_t n)
int puts(const char *s)
int mini_itoa(long value, unsigned int radix, int uppercase, int unsig,
	 char *buffer)
int mini_vsnprintf(char *buffer, unsigned int buffer_len, const char *fmt, va_list va)
int mini_vpprintf(int (*puts)(char* s, int len, void* buf), void* buf, const char *fmt, va_list va)
int mini_snprintf(char* buffer, unsigned int buffer_len, const char *fmt, ...)
int mini_pprintf(int (*puts)(char*s, int len, void* buf), void* buf, const char *fmt, ...)

// IRQ Handling Code
void DefaultIRQHandler( void )
void NMI_RCC_CSS_IRQHandler( void )

// Startup Code
void InterruptVectorDefault( void )
void handle_reset( void )

// Configuration-specific I/O

#if defined( FUNCONF_USE_UARTPRINTF ) && FUNCONF_USE_UARTPRINTF
void SetupUART( int uartBRR )
int _write(int fd, const char *buf, int size)
int putchar(int c)
#endif

#if defined( FUNCONF_USE_DEBUGPRINTF ) && FUNCONF_USE_DEBUGPRINTF
void handle_debug_input( int numbytes, uint8_t * data ) // You can override this!
void poll_input( void )
int _write(int fd, const char *buf, int size)
int putchar(int c)
void SetupDebugPrintf( void )
void WaitForDebuggerToAttach()
#endif

#if (defined( FUNCONF_USE_DEBUGPRINTF ) && !FUNCONF_USE_DEBUGPRINTF) && \
    (defined( FUNCONF_USE_UARTPRINTF ) && !FUNCONF_USE_UARTPRINTF) && \
    (defined( FUNCONF_NULL_PRINTF ) && FUNCONF_NULL_PRINTF)

int _write(int fd, const char *buf, int size)
int putchar(int c)
#endif

void DelaySysTick( uint32_t n )
void SystemInit( void )

#ifdef CPLUSPLUS
extern void __cxa_pure_virtual()
void __libc_init_array(void)
#endif

*/

// We pre-define these, because if the user is (for some awful reason) using gcc-riscv64-linux-gnu with newlib, it will fail to compile if it janks up the stdio/string functions.
#define _SSP_STRING_H_
#define _SSP_STDIO_H_

#include <stdio.h>
#include <string.h>
#include <stdarg.h>
#include <limits.h>
#include <stdint.h>
#include <ch32fun.h>

#define WEAK __attribute__((weak))

WEAK int errno;

static int __puts_uart( char *s, int len, void *buf )
{
	(void)buf;

	_write( 0, s, len );
	return len;
}

WEAK int printf( const char* format, ... )
{
	va_list args;
	va_start( args, format );
	int ret_status = mini_vpprintf(__puts_uart, 0, format, args);
	va_end( args );
	return ret_status;
}

WEAK int vprintf(const char* format, va_list args)
{
	return mini_vpprintf(__puts_uart, 0, format, args);
}

WEAK int snprintf( char * buffer, unsigned int buffer_len, const char* format, ... )
{
	va_list args;
	va_start( args, format );
	int ret = mini_vsnprintf( buffer, buffer_len, format, args );
	va_end( args );
	return ret;
}

WEAK int sprintf( char * buffer, const char * format, ... )
{
	va_list args;
	va_start( args, format );
	int ret = mini_vsnprintf( buffer, INT_MAX, format, args );
	va_end( args );
	return ret;
}

/* Some stuff from MUSL


----------------------------------------------------------------------
Copyright © 2005-2020 Rich Felker, et al.

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
THE SOFTWARE IS PROVIDED "AS IS", WITHOUT WARRANTY OF ANY KIND,
EXPRESS OR IMPLIED, INCLUDING BUT NOT LIMITED TO THE WARRANTIES OF
MERCHANTABILITY, FITNESS FOR A PARTICULAR PURPOSE AND NONINFRINGEMENT.
IN NO EVENT SHALL THE AUTHORS OR COPYRIGHT HOLDERS BE LIABLE FOR ANY
CLAIM, DAMAGES OR OTHER LIABILITY, WHETHER IN AN ACTION OF CONTRACT,
TORT OR OTHERWISE, ARISING FROM, OUT OF OR IN CONNECTION WITH THE
SOFTWARE OR THE USE OR OTHER DEALINGS IN THE SOFTWARE.
----------------------------------------------------------------------

*/

/*
 * mbstate_t is an opaque object to keep conversion state, during multibyte
 * stream conversions.  The content must not be referenced by user programs.
 */

#define CURRENT_UTF8 0
#define IS_CODEUNIT(c) ((unsigned)(c)-0xdf80 < 0x80)
#define MB_CUR_MAX (CURRENT_UTF8 ? 4 : 1)

typedef void * mbstate_t;

#ifdef UNICODE
WEAK size_t wcrtomb(char *restrict s, wchar_t wc, mbstate_t *restrict st)
{
	if (!s) return 1;
	if ((unsigned)wc < 0x80) {
		*s = wc;
		return 1;
	} else if (MB_CUR_MAX == 1) {
		if (!IS_CODEUNIT(wc)) {
			errno = 0x02; // EILSEQ
			return -1;
		}
		*s = wc;
		return 1;
	} else if ((unsigned)wc < 0x800) {
		*s++ = 0xc0 | (wc>>6);
		*s = 0x80 | (wc&0x3f);
		return 2;
	} else if ((unsigned)wc < 0xd800 || (unsigned)wc-0xe000 < 0x2000) {
		*s++ = 0xe0 | (wc>>12);
		*s++ = 0x80 | ((wc>>6)&0x3f);
		*s = 0x80 | (wc&0x3f);
		return 3;
	} else if ((unsigned)wc-0x10000 < 0x100000) {
		*s++ = 0xf0 | (wc>>18);
		*s++ = 0x80 | ((wc>>12)&0x3f);
		*s++ = 0x80 | ((wc>>6)&0x3f);
		*s = 0x80 | (wc&0x3f);
		return 4;
	}
	errno = 0x02;//EILSEQ;
	return -1;
}
WEAK int wctomb(char *s, wchar_t wc)
{
	if (!s) return 0;
	return wcrtomb(s, wc, 0);
}
#endif
WEAK size_t strlen(const char *s)
{
	const char *a = s;
	for (; *s; s++);
	return s-a;
}
WEAK size_t strnlen(const char *s, size_t n) { const char *p = memchr(s, 0, n); return p ? (size_t)(p-s) : n;}
WEAK void *memset(void *dest, int c, size_t n) { unsigned char *s = dest; for (; n; n--, s++) *s = c; return dest; }
WEAK char *strcpy(char *d, const char *s)
{
	char *d0=d;
	for (; (*d=*s); s++, d++);
	return d0;
}
WEAK char *strncpy(char *d, const char *s, size_t n)
{
	char *d0=d;
	for (; n && (*d=*s); n--, s++, d++);
	return d0;
}
WEAK int strcmp(const char *l, const char *r)
{
	for (; *l==*r && *l; l++, r++);
	return *(unsigned char *)l - *(unsigned char *)r;
}
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

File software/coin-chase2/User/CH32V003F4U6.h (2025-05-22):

/*
 * CH32V003F4U6.h
 *
 *  Created on: Apr 29, 2025
 *      Author: mlp
 */

#ifndef USER_CH32V003F4U6_H_
#define USER_CH32V003F4U6_H_
#include <ch32v00x.h>

//refman 6.5.4.1 System Count Control Register (STK_CTLR)
#define	STK_CTLR_SWIE	(1u<<31)	//trigger software interrupt
#define	STK_CTLR_STRE	(1u<<3)	//auto-reload
#define	STK_CTLR_STCLK	(1u<<2)	//HCLK /1 not /8
#define	STK_CTLR_STIE	(1u<<1)	//counter interrupt enable
#define	STK_CTLR_STE	(1u<<0)	//counter enable

//refman 6.5.4.2 System Count Status Register (STK_SR)
#define	STK_SR_CNTIF	(1u<<0)	//write 0 => clear comparison


enum package_pins {
	PD7,
	PA1,
	PA2,
	VSS,
	PD0,

	VDD,
	PC0,
	PC1,
	PC2,
	PC3,

	PC4,
	PC5,
	PC6,
	PC7,
	PD1,

	PD2,
	PD3,
	PD4,
	PD5,
	PD6,

	total_package_pins
};

void set_pin(int pinID, int value);


#if REMAP == 00
#define UCK	PD4
#define A7	PD4
#define OPO	PD4
#define TIM2_ETR	PD4

#define UTX	PD5
#define A5	PD5
#define URX	PD6
#define A6	PD6

#define NRST	PD7
#define OPP1	PD7

#define A1	PA1
#define OPN0	PA1

#define A0	PA2
#define OPP0	PA2
#define TIM1_CH2N	PA2

#define OPN1	PD0
#define TIM1_CH1N	PD0

#define SDA	PC1
#define NSS	PC1

#define SCL	PC2
#define URTS	PC2
#define TIM1_BKIN	PC2

#define MCO	PC4
#define A2	PC4

#define SCK	PC5
#define TIM1_ETR	PC5

#define MOSI	PC6
#define MISO	PC7

#define SWIO	PD1
#define TIM1_CH3N	PD1
#define AETR2	PD1

#define A3	PD2

#define A4	PD3
#define AETR	PD3
#define UCTS	PD3

#define TIM1_CH1	PD2
#define TIM1_CH2	PA1
#define TIM1_CH3	PC3
#define TIM1_CH4	PC4

#define TIM2_CH1	PD4
#define TIM2_CH2	PD3
#define TIM2_CH3	PC0
#define TIM2_CH4	PD7

#elif REMAP == 01
#define TIM1_CH1	PC6
#define TIM1_CH2	PC7
#define TIM1_CH3	PC0
#define TIM1_CH4	PD3

#define TIM2_CH1	PC5
#define TIM2_CH2	PC2
#define TIM2_CH3	PD2
#define TIM2_CH4	PC1

#elif REMAP == 10
#define TIM1_CH1	PD2
#define TIM1_CH2	PA1
#define TIM1_CH3	PC3
#define TIM1_CH4	PC4

#define TIM2_CH1	PC1
#define TIM2_CH2	PD3
#define TIM2_CH3	PC0
#define TIM2_CH4	PD7

#elif REMAP == 11
#define TIM1_CH1	PC4
#define TIM1_CH2	PC7
#define TIM1_CH3	PC5
#define TIM1_CH4	PD4

#define TIM2_CH1	PC1
#define TIM2_CH2	PC7
#define TIM2_CH3	PD6
#define TIM2_CH4	PD5

#else
#error bad REMAP
#endif

#endif /* USER_CH32V003F4U6_H_ */

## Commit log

2024-12-03 add locations for JLCPCB order IDs
    [coin1.kicad_pcb]
2024-12-03 add LCSC part details
    [coin1.kicad_pcb, coin1.kicad_sch]
2024-12-03 use pin headers for their pads only
    [coin1.kicad_sch]
2024-12-03 made a version with 0402 rather than 0201 R&D
    [coin2.kicad_pcb, coin2.kicad_sch]
2024-12-03 route and DRC the new board
    [coin2.kicad_pcb]
2024-12-04 cleanup some hole locations etc.
    [coin2.kicad_pcb, coin2.kicad_sch]
2024-12-04 add bypass caps, tweak clearance holes
    [coin2.kicad_pcb, coin2.kicad_sch]
2024-12-05 change connectors from 2.54 to 1.27mm spacing, add decoupling
    [coin2.kicad_pcb, coin2.kicad_sch]
2024-12-05 separate models and make explicit
    [smd0201.kicad_pcb, smd0201.kicad_sch, smd0402.kicad_pcb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]
2024-12-05 improve DRC
    [smd0402.kicad_pcb]
2024-12-05 separate boards, generate fab output
    [b1-BOM.csv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]
2024-12-05 adjust BOM+POS files for JLCPCB
    [b1-BOM.csv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]
2024-12-05 add LIMITED EDITION text
    [smd0402.kicad_pcb]
2024-12-05 make LIMITED EDITION be bare copper
    [smd0402.kicad_pcb]
2024-12-05 update fab output
    [b4-B_Cu.gbl, b4-B_Mask.gbs, b4-B_Paste.gbp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]
2024-12-05 add repo URL QR on back, tweak text on front
    [smd0402.kicad_pcb]
2024-12-05 tweak toward JLC assembly files
    [smd0402.kicad_sch]
2024-12-05 refreshed fab files
    [b1-BOM.csv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]
2024-12-05 convert KiCad to JLC format
    [reverse-BOM.csv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]
2024-12-05 forgot to nuke unplaced jumpers
    [reverse-top-pos.csv]
2024-12-05 and nuke unused column
    [reverse-top-pos.csv]
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2025-01-10 missed a pin
2025-01-10 also missed initialising GPIOC clock - now it blinks
    [main.c]
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2025-02-03 moved clearance holes to match decoupling caps
    [smd0402.kicad_pcb]
2025-02-04 reassign touch pads to OPNx
    [smd0402.kicad_pcb, smd0402.kicad_sch]
2025-02-04 look long and hard at LED-driving pins
    [WCH32V003 alt func and remapping.ods]
2025-02-04 reassign pins for LEDs and touchpads
    [smd0402.kicad_pcb, smd0402.kicad_sch]
2025-02-04 change bypass caps from 10n to 1u
    [smd0402.kicad_pcb, smd0402.kicad_sch]
2025-02-06 add some docs on GPIO remapping
    [WCH32V003 alt func and remapping.ods]
2025-02-06 lose NRST, use TIM2 default mapping
    [smd0402.kicad_pcb, smd0402.kicad_sch]
2025-02-06 re-route a couple LED signals
    [smd0402.kicad_pcb]
2025-02-06 tweak pin allocations
    [WCH32V003 alt func and remapping.ods]
2025-02-12 add some used pins
    [WCH32V003 alt func and remapping.ods]
2025-02-14 boost dia to 50mm, use back-to-back LEDs, add SAO
    [smd0402.kicad_pcb, smd0402.kicad_sch]
2025-02-14 document back-to-back LEDs
    [WCH32V003 alt func and remapping.ods]
2025-02-15 clean up DRC
    [smd0402.kicad_pcb]
2025-02-15 add via-stitching
    [smd0402.kicad_pcb]
2025-02-15 final DRC cleanup
    [smd0402.kicad_pcb]
2025-02-16 separate boards and generate fab files
    [SAO-CR1616-B_Cu.gbl, SAO-CR1616-B_Mask.gbs, SAO-CR1616-B_Paste.gbp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]
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2025-02-26 convert to Kicad 9
    [smd0402.kicad_pcb, smd0402.kicad_sch]
2025-02-26 add SAO display board
    [smd0402.kicad_sch]
2025-02-26 created board
    [smd0402.kicad_pcb]
2025-02-26 added power bypass caps
    [smd0402.kicad_pcb, smd0402.kicad_sch]
2025-02-26 separate into fab-able parts
    [SAO-CR1616.kicad_pcb, SAO-CR1616.kicad_sch, internal.kicad_pcb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]
2025-02-26 update fab files
    [SAO-CR1616-B_Cu.gbl, SAO-CR1616-B_Mask.gbs, SAO-CR1616-B_Paste.gbp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]
2025-02-26 remove 4 bogus segments from edge cuts
    [SAO-CR1616.kicad_pcb]
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2025-02-26 regenerate fab files
    [SAO-CR1616-B_Cu.gbl, SAO-CR1616-B_Mask.gbs, SAO-CR1616-B_Paste.gbp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]
2025-02-26 because I moved some text
    [SAO-CR1616.kicad_pcb]
2025-02-26 regen fab files
    [reverse-BoM.csv, reverse.csv, reverse.kicad_pcb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]
2025-02-27 make mousebite holes 0.3mm
    [SAO-CR1616-B_Cu.gbl, SAO-CR1616-B_Mask.gbs, SAO-CR1616-B_Paste.gbp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]
2025-02-27 panelize for assembly
    [reverse-panel-BoM.csv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]
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2025-05-22 replace switch/case with table lookup
    [CH32V003F4U6.h, main.c]
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2025-06-03 hash area fill; un-plate MCU clearance hole
    [smd0402.kicad_pcb]
2025-06-09 shrink touchpad to 8mm circle
    [smd0402.kicad_pcb]
2025-06-12 add 2 alignment holes to each outer layer
    [smd0402.kicad_pcb]
2025-06-12 remove SAO display
    [smd0402.kicad_pcb, smd0402.kicad_sch]
2025-06-12 cleanup fab files
    [SAO-CR1616-B_Cu.gbl, SAO-CR1616-B_Mask.gbs, SAO-CR1616-B_Paste.gbp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]
2025-06-13 change text
    [smd0402.kicad_pcb]
2025-06-13 reduce maskless copper; tweak font
    [smd0402.kicad_pcb]
2025-06-13 cleaned up pads; relocated repo QR
    [smd0402.kicad_pcb]
2025-06-13 ready to panelize 4 reverse boards
    [reverse-panel-cleaned.kicad_pcb]
2025-06-13 integrated final assembly instructions
    [smd0402.kicad_pcb]
2025-06-13 tweak instructions
    [smd0402.kicad_pcb]
2025-06-13 update rails+mousebites empty panel
    [reverse-panel-cleaned.kicad_pcb]
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2025-06-13 rebuild panel with all SWD ports toward outside
    [reverse-panel.kicad_pcb]
2025-06-14 make clearance-holes less likely to contact
    [smd0402.kicad_pcb]
2025-06-15 update parts to those in stock at JLC *now*
    [smd0402.kicad_sch]
2025-06-15 separate sandwich layers to generate fab files
    [internal.kicad_pcb]
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2025-06-15 add tooling holes; relocate fiducials
    [reverse-panel-cleaned.kicad_pcb]
2025-06-16 add tooling holes; relocate fiducials; cleanup
    [reverse-panel-cleaned.kicad_pcb]
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2025-07-17 latest separated fabricated boards
    [internal.kicad_pcb, reverse.kicad_pcb]
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2025-07-27 try to avoid breaking the debug I/O
    [main.c]
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2025-08-26 prep for another fab run
    [SAO-CR1616.kicad_pcb, internal.kicad_pcb, reverse.kicad_pcb]
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

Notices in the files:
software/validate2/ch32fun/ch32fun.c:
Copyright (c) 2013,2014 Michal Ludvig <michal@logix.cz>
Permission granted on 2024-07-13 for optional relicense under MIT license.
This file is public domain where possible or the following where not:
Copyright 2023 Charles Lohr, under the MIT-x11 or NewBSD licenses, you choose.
